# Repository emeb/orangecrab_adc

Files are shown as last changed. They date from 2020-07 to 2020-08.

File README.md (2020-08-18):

# orangecrab_adc
An ADC and audio FeatherWing to enable SDR experiments with the OrangeCrab

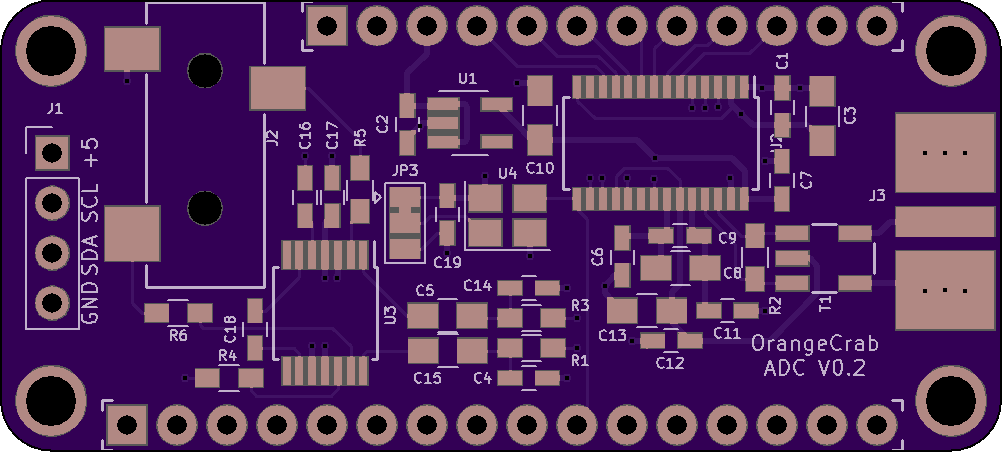
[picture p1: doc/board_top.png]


## What is it?
This is an experiment to see if a low-spec SDR system can be easily built
using the OrangeCrab FPGA Feather. It will consist of the ADC / Audio 
"FeatherWing" board which attaches to the OrangeCrab board, along with
gateware to do basic tuning and demodulation. Initial testing will be
static setups, or controlled by USB, but the project may be expanded with
a UI board containing display and buttons / encoders.

## Features
The board comprises the following components:

* AD9203 10-bit / 40MSPS parallel ADC
* 40MHz crystal oscillator
* Analog supply regulation
* 50-ohm SMA input with transformer-coupling to the converter
* TPA6139 Headphone amplifier and 3.5mm jack
* 4-pin I2C bus extension (power, clock, data, gnd)

## Schematic
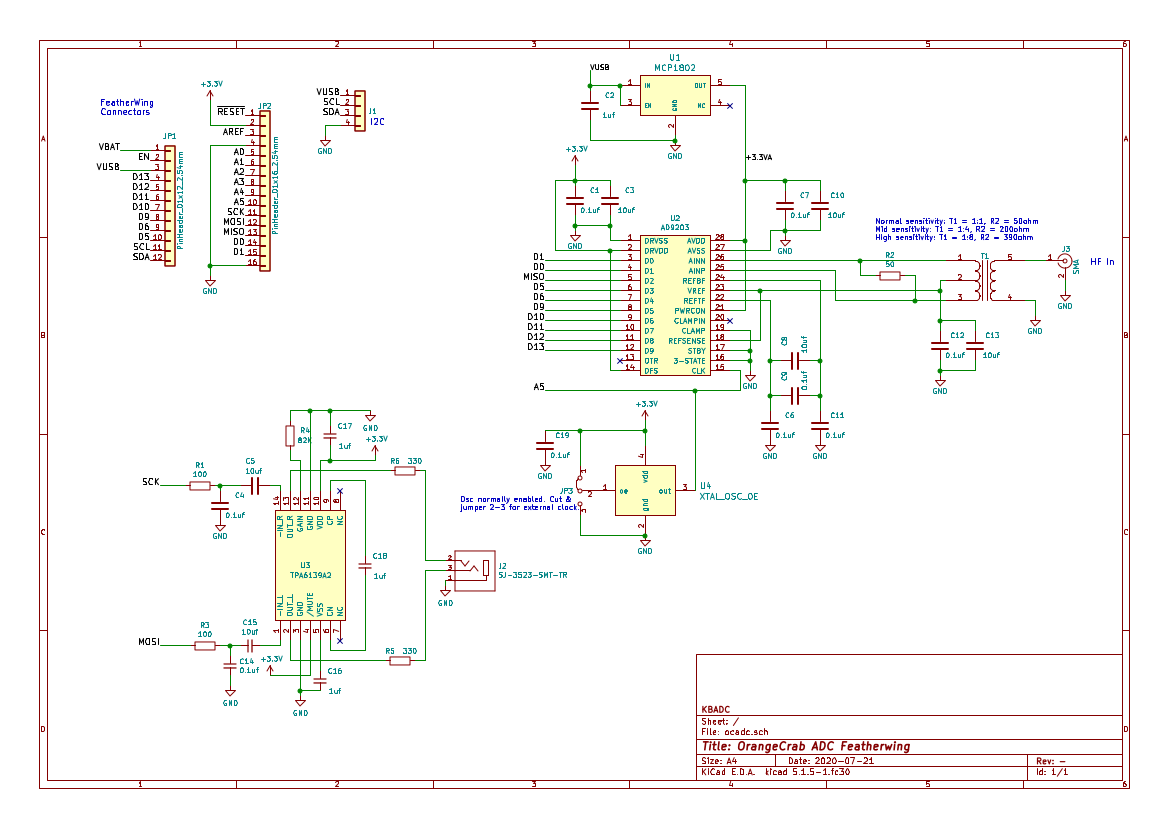
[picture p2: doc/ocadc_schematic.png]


## Status
* 2020-07-24: The preliminary board design is complete and boards have been
ordered from OSHPark. Parts have been ordered so initial testing should occurr
sometime in early August 2020.

* 2020-08-08: Boards are back from OSHpark and the preliminary test gateware
is working for simple AM broadcast reception. Audio output sounds great -
very clean and clear. 

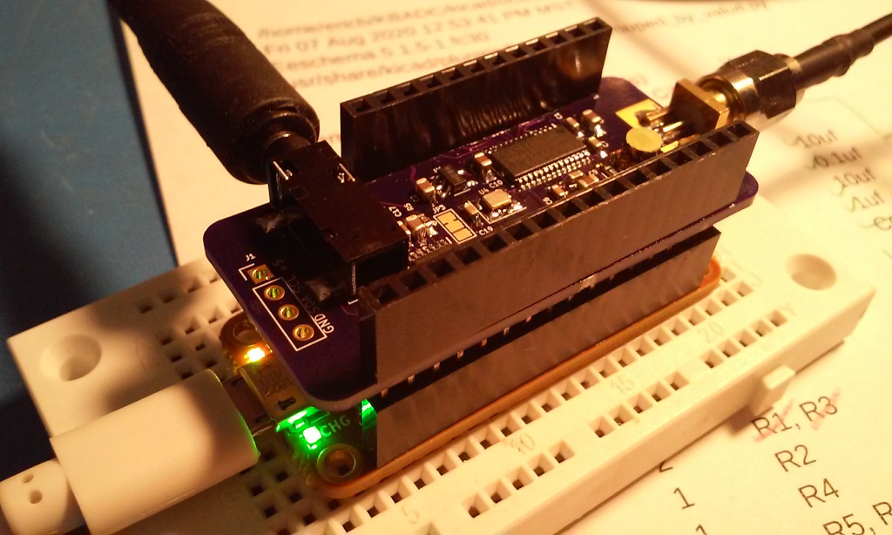
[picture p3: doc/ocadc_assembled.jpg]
assembled board


* 2020-08-09: Corrected missing mount holes in PCB. Updated OSHpark link

https://oshpark.com/shared_projects/GzvQCkin

* 2020-08-18: Added Litex-based controller project

https://github.com/emeb/OrangeCrab-Litex-ADC

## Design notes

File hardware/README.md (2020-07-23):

# orangecrab_adc - hardware
Hardware design for the orangecrab_adc

This is just the KiCad design. The libraries are probably hosed (as usual)
because your setup isn't the same as mine. Hopefully the rescue libs and
cache have enough that you can see things.

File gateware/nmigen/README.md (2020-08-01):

# OrangeCrab ADC nMigen gateware
This is a *very* preliminary nMigen implementation of a decimating
downconverter (DDC) for use with the OrangeCrab ADC featherwing. The system
architecture is based on the same structure that has been used for most of
the other SDR projects I've done, with some minor tweaks for the ECP5
capabilities.

Don't laugh - this is the first substantial nMigen code I've written and it's
mostly based on reading random tutorials, a few examples and banging my head
against the wall. I'm sure there's a fair amount of non-optimal coding style
in here - feel free to critque it.

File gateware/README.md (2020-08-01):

# Gateware
This directory contains gateware for the OrangeCrab ADC project. There are
two different approaches taken:

## Verilog
This is a design based on Verilog source code taken from previous projects. 
To build it:

    cd verilog/trellis
    make

This will generate the .dfu file needed for programming the OrangeCrab. To
program use the following command:

    make dfu

## nMigen
This is a design based on nMigen source code. The architecture of this is
nearly identical to that of the Verilog design, but the HDL used is very
different. To build it:

    cd nmigen
    python3 top.py
    cd build
    source build_top.sh
    cp top.bit top.dfu
    dfu-suffix -v 1209 -p 5af0 -a top.dfu

This will generate the raw bitstream .bit file and the .dfu file needed for
programming the OrangeCrab. To program use the following command:

    dfu-util -D top.dfu

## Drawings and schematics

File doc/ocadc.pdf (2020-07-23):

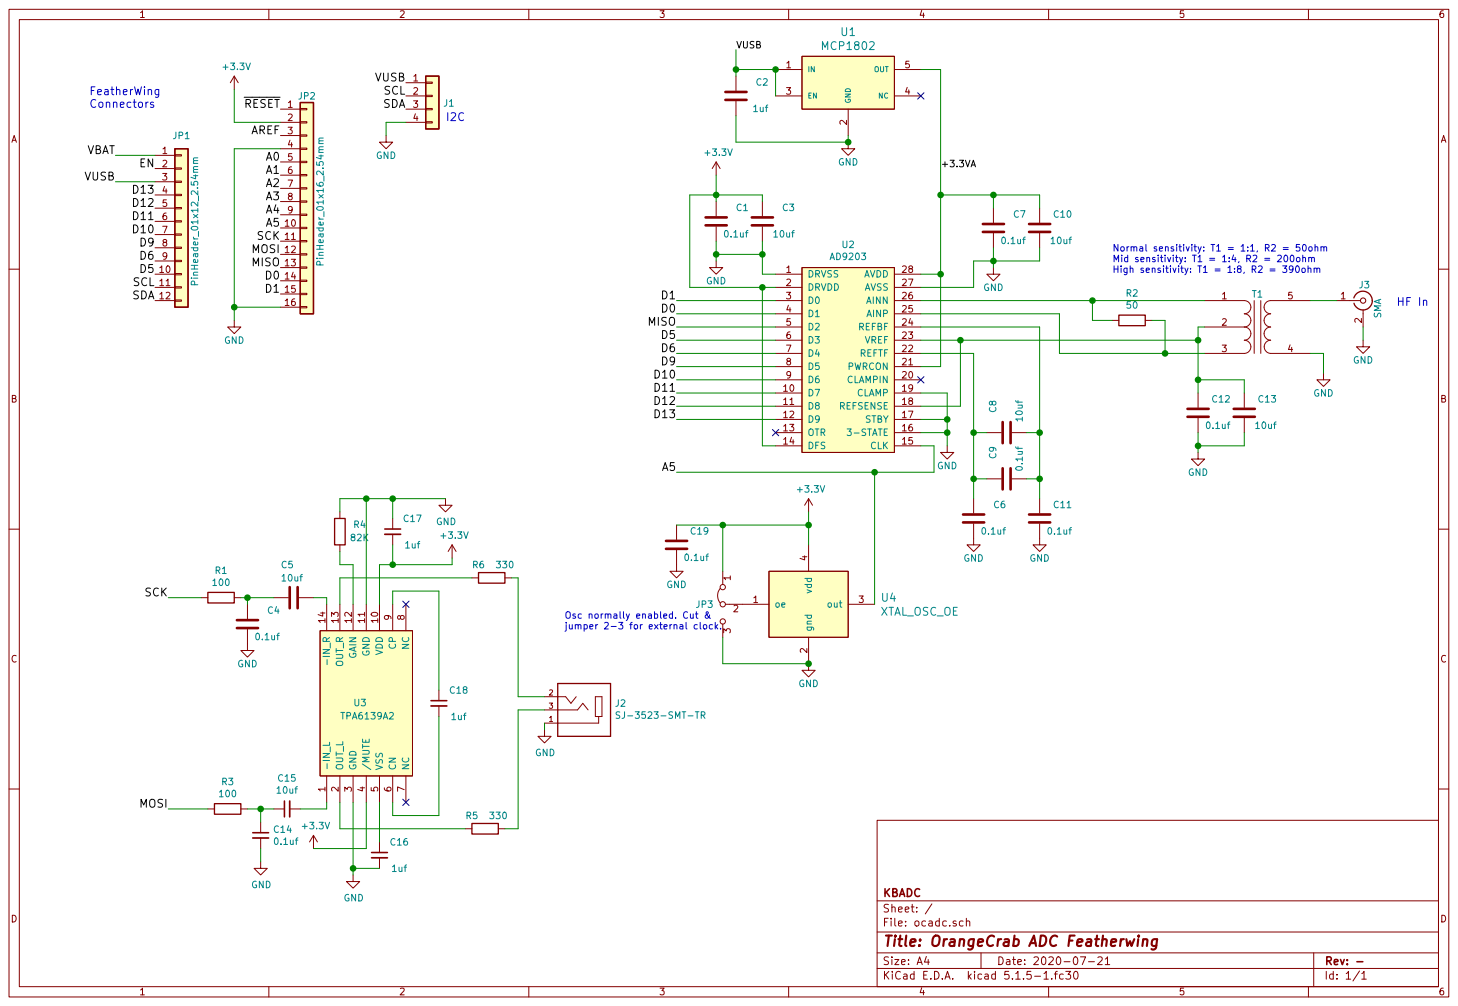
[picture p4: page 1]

HF In Normal sensitivity: T1 = 1:1, R2 = 50ohm
Mid sensitivity: T1 = 1:4, R2 = 200ohm
High sensitivity: T1 = 1:8, R2 = 390ohm

Osc normally enabled. Cut &
jumper 2-3 for external clock.

File: ocadc.sch Sheet: / KBADC

Id: 1/1 Title: OrangeCrab ADC Featherwing

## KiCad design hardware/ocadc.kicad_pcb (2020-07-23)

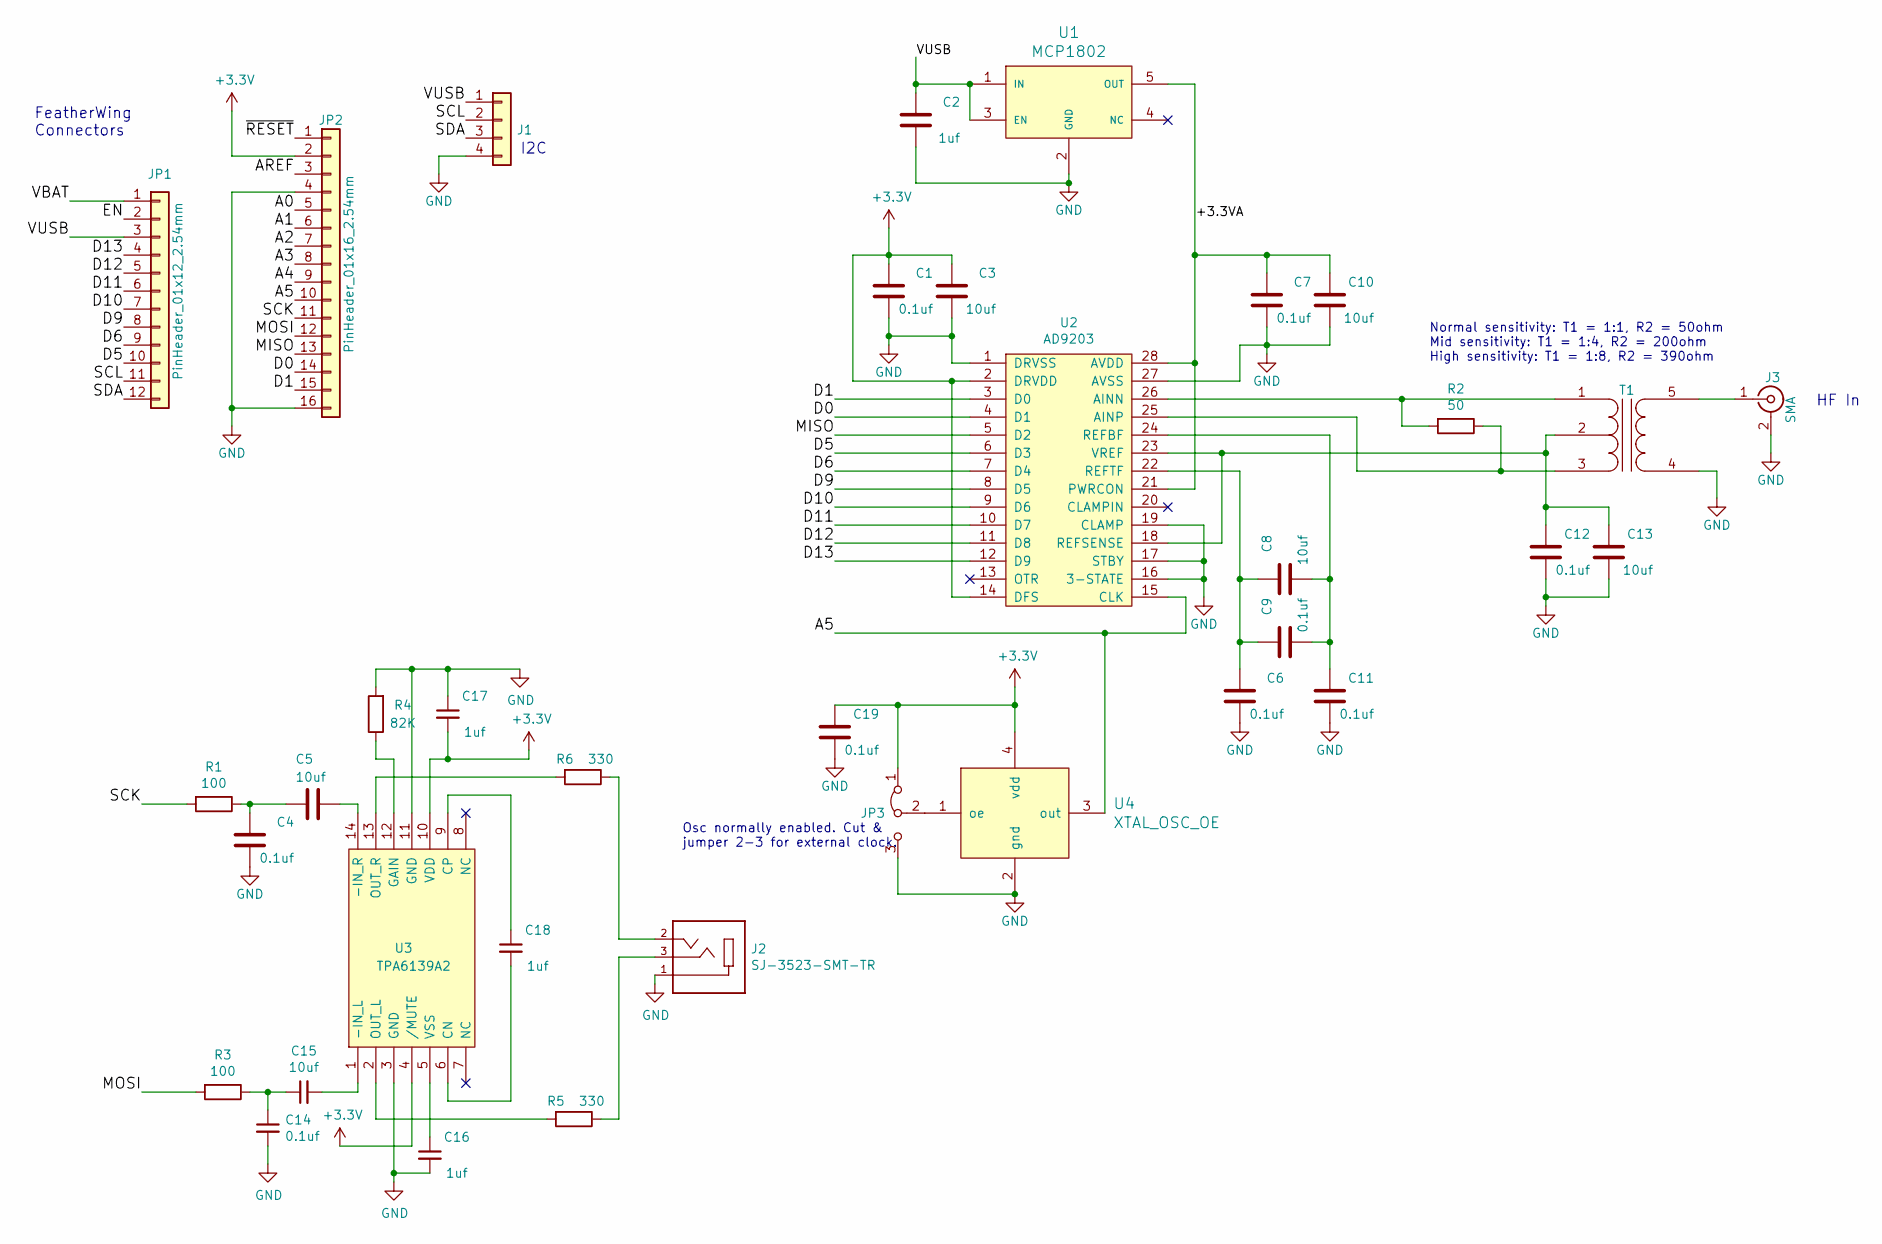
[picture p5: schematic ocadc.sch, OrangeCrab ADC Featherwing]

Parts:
C1, C4, C6, C7, C9, C11, C12, C14, C19: 0.1uf; C_0603_HandSoldering
C2, C16, C17, C18: 1uf; C_0603_HandSoldering
C3, C5, C8, C10, C13, C15: 10uf; C_0805_HandSoldering
J1: Conn_01x04; Pin_Header_Straight_1x04_Pitch2.54mm
J2: SJ-3523-SMT-TR; CUI_SJ-3523-SMT-TR
J3: SMA; SMA_END
JP1: PinHeader_01x12_2.54mm; Conn_PinHeader_1x12
JP2: PinHeader_01x16_2.54mm; Conn_PinHeader_1x16
JP3: Jumper_3_Bridged12; SolderJumper-3_P1.3mm_Bridged12_Pad1.0x1.5mm
R1, R3: 100; R_0603_HandSoldering
R2: 50; R_0603_HandSoldering
R4: 82K; R_0603_HandSoldering
R5, R6: 330; R_0603_HandSoldering
T1: TRANSFO4; Pulse_SMD_Balun
U1: MCP1802; SOT-23-5_HandSoldering
U2: AD9203; TSSOP-28_4.4x9.7mm_Pitch0.65mm
U3: TPA6139A2; TSSOP-14_4.4x5mm_Pitch0.65mm
U4: XTAL_OSC_OE; Oscillator_SMD_SeikoEpson_SG210-4pin_2.5x2.0mm_HandSoldering

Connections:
+3V3: C1.2, C3.2, C17.2, C19.2, JP2.2, JP3.1 (A), U2.2 (DRVDD), U2.14 (DFS), U3.4 (/MUTE), U3.10 (VDD), U4.4 (vdd)
/+3.3VA: C7.2, C10.2, U1.5 (OUT), U2.21 (PWRCON), U2.28 (AVDD)
/A0: JP2.5
/A1: JP2.6
/A2: JP2.7
/A3: JP2.8
/A4: JP2.9
/A5: JP2.10, U2.15 (CLK), U4.3 (out)
/AREF: JP2.3
/D0: JP2.14, U2.4 (D1)
/D1: JP2.15, U2.3 (D0)
/D5: JP1.10, U2.6 (D3)
/D6: JP1.9, U2.7 (D4)
/D9: JP1.8, U2.8 (D5)
/D10: JP1.7, U2.9 (D6)
/D11: JP1.6, U2.10 (D7)
/D12: JP1.5, U2.11 (D8)
/D13: JP1.4, U2.12 (D9)
/EN: JP1.2
/MISO: JP2.13, U2.5 (D2)
/MOSI: JP2.12, R3.2
/SCK: JP2.11, R1.2
/SCL: J1.2, JP1.11
/SDA: J1.3, JP1.12
/VBAT: JP1.1
/VUSB: C2.2, J1.1, JP1.3, U1.1 (IN), U1.3 (EN)
/~RESET: JP2.1
GND: C1.1, C2.1, C3.1, C4.1, C6.1, C7.1, C10.1, C11.1, C12.1, C13.1, C14.2, C16.2, C17.1, C19.1, J1.4, J2.1, J3.2 (Ext), JP2.4, JP2.16, JP3.3 (B), R4.2, T1.4 (S1), U1.2 (GND), U2.1 (DRVSS), U2.16 (3-STATE), U2.17 (STBY), U2.19 (CLAMP), U2.27 (AVSS), U3.3 (GND), U3.11 (GND), U4.2 (gnd)
unnamed: C4.2, C5.2, R1.1
unnamed: C5.1, U3.14 (-IN_R)
unnamed: C6.2, C8.2, C9.2, U2.22 (REFTF)
unnamed: C8.1, C9.1, C11.2, U2.24 (REFBF)
unnamed: C12.2, C13.2, T1.2 (PM), U2.18 (REFSENSE), U2.23 (VREF)
unnamed: C14.1, C15.1, R3.1
unnamed: C15.2, U3.1 (-IN_L)
unnamed: C16.1, U3.5 (VSS)
unnamed: C18.1, U3.9 (CP)
unnamed: C18.2, U3.6 (CN)
unnamed: J2.2, R6.1
unnamed: J2.3, R5.1
unnamed: J3.1 (In), T1.5 (S2)
unnamed: JP3.2 (C), U4.1 (oe)
unnamed: R2.1, T1.3 (PR2), U2.25 (AINP)
unnamed: R2.2, T1.1 (PR1), U2.26 (AINN)
unnamed: R4.1, U3.12 (GAIN)
unnamed: R5.2, U3.2 (OUT_L)
unnamed: R6.2, U3.13 (OUT_R)

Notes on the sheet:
HF In
FeatherWing Connectors
I2C
Normal sensitivity: T1 = 1:1, R2 = 50ohm Mid sensitivity: T1 = 1:4, R2 = 200ohm High sensitivity: T1 = 1:8, R2 = 390ohm
Osc normally enabled. Cut & jumper 2-3 for external clock.

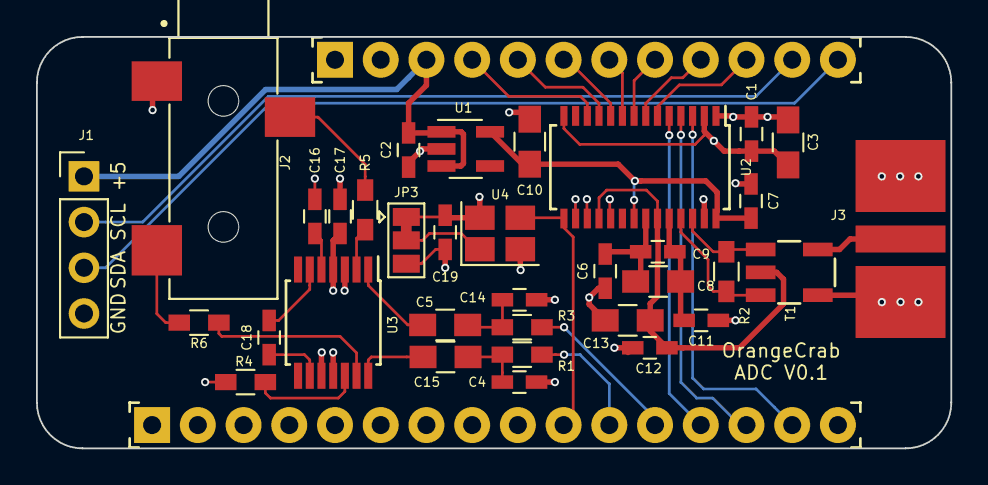
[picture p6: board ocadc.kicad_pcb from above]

Board: 4 copper layers, 50.8 x 22.9 mm, 36 parts (0 on the bottom side), 38 nets.

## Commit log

2020-07-23 Initial checkin of ocadc materials
    [ocadc.kicad_pcb, ocadc.sch]
2020-08-08 Updated with working board
2020-08-09 Update PCB permalink for V0.2

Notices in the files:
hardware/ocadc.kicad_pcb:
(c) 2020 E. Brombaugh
